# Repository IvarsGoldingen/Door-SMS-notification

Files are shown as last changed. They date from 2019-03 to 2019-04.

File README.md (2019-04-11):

# Door SMS notification

A device that sends an SMS notification when a door is opened. Setup on Atmega Atmel 328P arduino prototyping board together with SIM900 board. The schematic, part layout on the prototyping board and code included in this repository.

## Functions

* SMS notification of door opened event;
* 3 modes: send always, never send, send depending on time;
* Uses RTC on the SIM900 module to evaluate if SMS needs to be sent or not if sending depending on time enabled;
* Sends notification if battery gets low;
* Indication lights.

## Photos



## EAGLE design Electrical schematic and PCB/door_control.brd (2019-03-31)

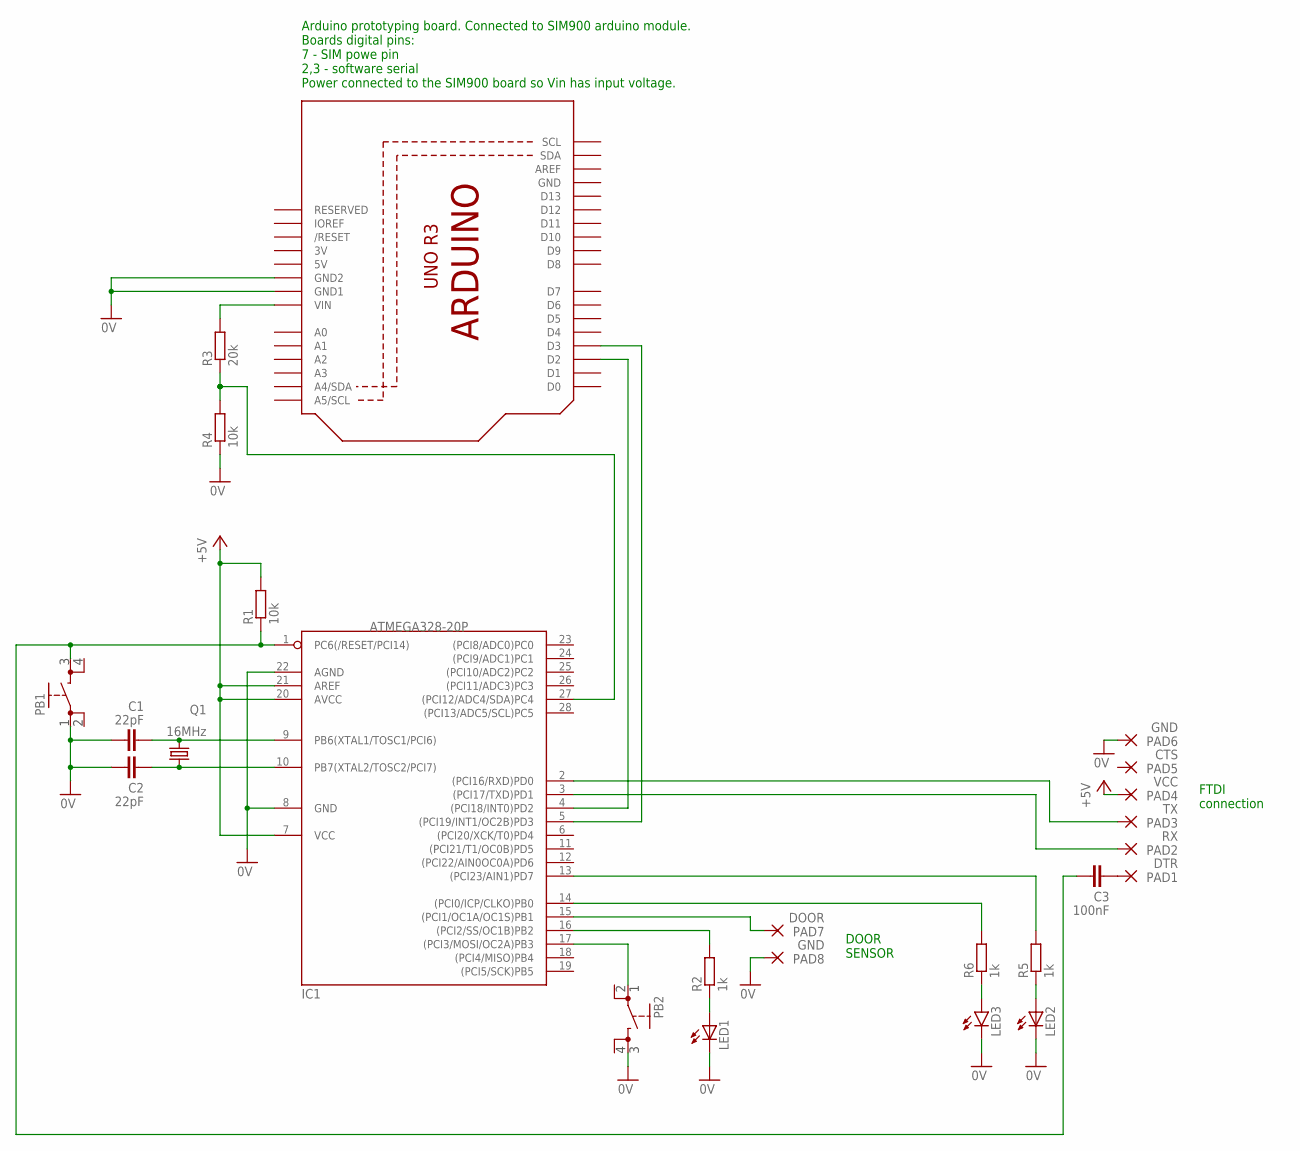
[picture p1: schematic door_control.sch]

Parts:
C1, C2: 22pF; C5B2.5
C3: 100nF; C10B4
IC1: ATMEGA328-20P; DIL28-3
LED1, LED2: LED_ELD260; LED_LD260
LED3: LED5MM
PAD1: DTR; 1,6/0,9
PAD2: RX; 1,6/0,9
PAD3: TX; 1,6/0,9
PAD4: VCC; 1,6/0,9
PAD5: CTS; 1,6/0,9
PAD6, PAD8: GND; 1,6/0,9
PAD7: DOOR; 1,6/0,9
PB1, PB2: 4P_BUTTONTH; 4P_BUTTON
Q1: 16MHz; HC49/S
R1: 10k; 0207/10
R2, R5, R6: 1k; 0204/5
R3: 20k; 0204/5
R4: 10k; 0204/5
U1: ARDUINOR3-DIMENSION; ARDUINOR3

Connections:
0V: C1.1, C2.1, IC1.8 (GND), IC1.22 (AGND), LED1.K (C), LED2.K (C), LED3.K (C), PAD6.1, PAD8.1, PB1.1, PB2.3, R4.1, U1.GND1, U1.GND2
3V: U1.3V
5V: U1.5V
+5V: IC1.7 (VCC), IC1.20 (AVCC), IC1.21 (AREF), PAD4.1, R1.2
GND: U1.GND
unnamed: C1.2, IC1.9 (PB6(XTAL1/TOSC1/PCI6)), Q1.2
unnamed: C2.2, IC1.10 (PB7(XTAL2/TOSC2/PCI7)), Q1.1
unnamed: C3.1, IC1.1 (PC6(/RESET/PCI14)), PB1.3, R1.1
unnamed: IC1.3 ((PCI17/TXD)PD1), PAD2.1
unnamed: IC1.2 ((PCI16/RXD)PD0), PAD3.1
unnamed: C3.2, PAD1.1
unnamed: IC1.15 ((PCI1/OC1A/OC1S)PB1), PAD7.1
unnamed: LED1.A, R2.1
unnamed: IC1.4 ((PCI18/INT0)PD2), U1.D2
unnamed: IC1.17 ((PCI3/MOSI/OC2A)PB3), PB2.1
unnamed: IC1.5 ((PCI19/INT1/OC2B)PD3), U1.D3
unnamed: IC1.27 ((PCI12/ADC4/SDA)PC4), R3.1, R4.2
unnamed: R3.2, U1.VIN
unnamed: IC1.13 ((PCI23/AIN1)PD7), R5.2
unnamed: LED2.A, R5.1
unnamed: IC1.14 ((PCI0/ICP/CLKO)PB0), R6.2
unnamed: LED3.A, R6.1
unnamed: IC1.16 ((PCI2/SS/OC1B)PB2), R2.2

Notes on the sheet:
FTDI connection
DOOR SENSOR
Arduino prototyping board. Connected to SIM900 arduino module. Boards digital pins: 7 - SIM powe pin 2,3 - software serial Power connected to the SIM900 board so Vin has input voltage.

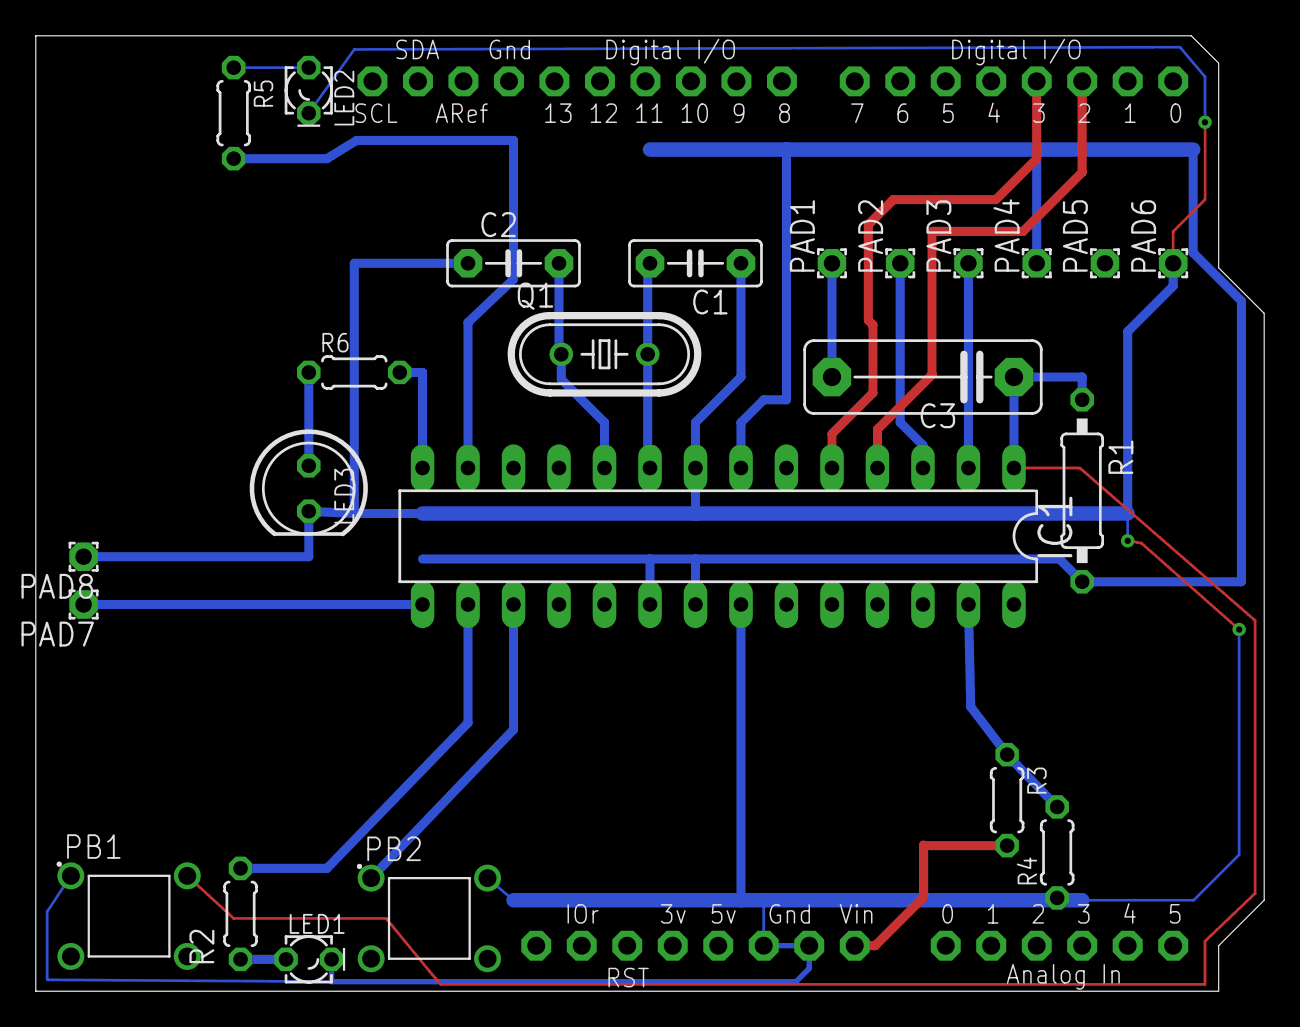
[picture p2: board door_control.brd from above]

Board: 2 copper layers, 68.6 x 53.3 mm, 25 parts (0 on the bottom side), 20 nets.

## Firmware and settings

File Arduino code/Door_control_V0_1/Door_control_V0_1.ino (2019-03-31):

/*
 * DOOR CONTROL v0.1
 * Sketch sends SMS using sim900 module, when a door is opened
 * Sending possible in 3 modes: send always, send depending on time(RTC on SIM900), dont send
 * Button for togling modes
 * Manual control through serial available
 * TODOs:
 * Implement logging on SD card. Slot available on SIM module
 * Clock sysnc using SIM
 */

#include "Sim.h"
#include "ButtonIB.h"
#include "LedControl.h"

//Pin used to enable disable the SIM module
const byte SIM_ENABLE_P = 4;

//Voltage input connected to arduino with a voltage divider. I am using 10k and 20k.
//So the voltage read on the input is one third of the actual voltage
const byte VOLTGE_DIVIDER_K = 3;
//Voltage input pin
const byte V_PIN = 4;
//time between voltage measurements in s (If timer1 interrupt set to happen once a second)
const int V_RD_DLY = 900;//900/60=15min
//Values used to calculate the actual volts read on the analog input
const float VOLTS_PER_UNIT = 5.0/1023.0;
//Minumum voltage level, error message sent otherwise
const float MINIMUM_VOLTAGE = 5.0;

/**Status indication values**/
//Green led output. Const on SIM900 ready, blinking setting up
const int STATUS_LED_O = 8;
//Const on, when sim900 fails to setup
const int ERROR_LED_O = 7;

//Pins that will be used for the software serial to communicate with the sim900 chip
const byte SW_SERIAL_PIN1 = 2;
const byte SW_SERIAL_PIN2 = 3;

//Pin used for send mode change
const byte MODE_BUTTON = 11;
//Pin used for signaling of the current send mode of the system
const byte MODE_LED = 10;

//Door trigger values
const byte DOOR_SENSOR_P = 9;

//Minimum time necessary for the door open to be registered as an event.
const int MINIMUM_SWITCH_TIME = 1000;
//Set minimum time between door events 
//5 minutes = 5m * 60s * 1000ms = 300 000
const float DELAY_FOR_DOOR_EVENTS = 60000;

//Time constraints for when the sms is being sent
//returns 1 for Sunday, 2 for Monday, etc., up to 7 for Saturday
//the 2nd youngest bit represents Sunday, the oldest bit represents Saturday, the youngest bit does not represent anything
const byte SEND_WEEKDAYS = 0b01111100;
//Time of day from which SMS are sent on appropriate weekdays
const byte SEND_TIME_H_START = 8;
//Time of day from which SMS are np longer sent on approptiate weekdays
const byte SEND_TIME_H_END = 17;

//Manual control characters for serial port
//to set the time use this format x19/03/09,11:56:55+08,<yy/MM/dd,hh:mm:ss±zz> +08 for gmt+2,
//module must be on and initialized, that must be done mannualy before
const char SET_TIME_CHAR = 'x';
//returns the time stored in the sim module's RTC
const char GET_TIME_CHAR = 'y';
//change modes from don't send, send always, send depending on time
const char CHANGE_MODE_CHAR = 'm';
//turn module on and set PIN code
const char INIT_CHAR = 'e';
//turn module off
const char OFF_CHAR = 'o';
//sends test message when module is already initialized
const char TEST_MESSAGE_CHAR = 'w';
//full sequence, on, init, get time, send message, turn off
const char SEND_SEQUENCE_CHAR = 'a';

// 3 modes for sending
//Send depending on time
const byte SEND_TIME = 1;
//Send allways
const byte SEND_ALWAYS = 2;
//don't send
const byte SEND_OFF = 3;
//don't send
const byte LOW_BAT = 4;

//Set true when input voltage should be read
volatile bool readV = false;
//counter of timer interrupts to compare to with the V-RD_DLY int the ISR
volatile int vDlyCntr = 0;
//battery low indication
bool batteryLow = false;

bool doorTriggered = false;
//variable to store time since the last door moved, used for debounce
//set to negative MINIMUM_SWITCH_TIME so works instantly on startup
long doorMoveTime = -MINIMUM_SWITCH_TIME;
////variable to store time since the last door moved, used for setting delay between SMS sends 
long doorTriggerTime = -DELAY_FOR_DOOR_EVENTS;

//Made true when door is triggered
//when true the sim chip will get turned on, sms sent, then turned off
bool sending = false;
//variable of keeping track of the sending mode
byte sendMode = SEND_TIME;

//A buffer where the neccessary message is stored. At this point either "Door triggered" or battery low "possible"
char messageBuffer[16];

/*********************************************************************************
callback from the SIM library
must be declared before the contructur so the function is visible to it
Will inform the main scetch of finished actions and errors
possible status updates from Sim lib to main sketch
    const byte INIT_FINISHED = 1;
    const byte INIT_FAILED = 2;
    const byte SMS_SENT = 3;
    const byte SMS_SEND_FAILED = 4;
    const byte TUREND_OFF = 5;
*/
void updateCallback(byte message){
  Serial.println("CB");
  if (sending){
    //if sending started use info from SIM to send the message
    sendSequence(message);
  }
}

/*********************************************************************************
callback from the SIM library
must be declared before the contructur so the function is visible to it
sends time from SIM module's RTC
*/
void timeCallback(String simTime){
  //remove time zone from the string, which starts from index 17
  simTime.remove(17);
  Serial.println(simTime);
  if (sending){
    //determine what type of message is being sent
    if (messageBuffer[0] == 'D'){
      //A door triggered message is being sent
      //needs to be evaluated against modes and possibly time
      bool sendSMS = false;
      if (sendMode == SEND_OFF){
        Serial.println("Sending mode off");
      } else if (sendMode == SEND_TIME){
        sendSMS = evaluateSend(simTime);
      } else if (sendMode == SEND_ALWAYS){
        sendSMS = true;
        Serial.println("Sending mode allways");
      }
      if(sendSMS){
        Serial.println("Sending");
        float inputVoltage = readInputVoltage();
        //sendSms((char*)messageBuffer + '_' + simTime + '_' + "V:" + String(inputVoltage));
        String temp(messageBuffer);
        String fullMessage = temp + "\n" + simTime + "\nV: " + String(inputVoltage);
        Serial.println(fullMessage);
        sendSms(fullMessage);
      } else {
        stopSim();
        Serial.println("Not sending");
      }
      
    } else if (messageBuffer[0] == 'B'){
      //A battery low meessage is being sent
      float inputVoltage = readInputVoltage();
      String temp(messageBuffer);
      String fullMessage = temp + "\n" + simTime;
      Serial.println(fullMessage);
      sendSms(fullMessage);
    } else {
      Serial.println("Unknown message in message buffer");
    }
    
     
  }
}

//Create a Sim object to control the Sim900 chip
Sim sim(SW_SERIAL_PIN1,SW_SERIAL_PIN2,STATUS_LED_O,ERROR_LED_O, updateCallback, timeCallback);

//calback from the button object when a button is pressed
void modeButtonPressed(){
  //allow the button to override the low bat condition
  batteryLow = false;
  switchSendMode();
}

//A button object for receiving the mode change pressses
ButtonIB modeButton(MODE_BUTTON, modeButtonPressed);

LedControl modeLed(MODE_LED);

//Evaluates if sending of SMS is neccessary depending on send mode and time
//TODO: check only time here, and check for send off earlier
bool evaluateSend(String simTime){
  Serial.println("Evaluating send time");
   //-48 because the received number is from ASCII table not numeric
  byte year = ((simTime[0] - 48) * 10) + (simTime[1] - 48);
  byte month = ((simTime[3] - 48) * 10) + (simTime[4] - 48);
  byte day = ((simTime[6] - 48) * 10) + (simTime[7] - 48);
  byte hour = ((simTime[9] - 48) * 10) + (simTime[10] - 48);
  //byte minute = ((simTime[12] - 48) * 10) + (simTime[13] - 48);
  //byte second = ((simTime[15] - 48) * 10) + (simTime[16] - 48);
  byte weekDay = calcDayOfWeek(year, month, day);
  bool sendSMS = false;
  Serial.println(SEND_WEEKDAYS & (0b00000001 << weekDay));
  if((SEND_WEEKDAYS & (0b00000001 << weekDay)) > 0){
    Serial.println("Weekday");
    if(hour >= SEND_TIME_H_START &&
      hour < SEND_TIME_H_END){
      Serial.println("Working time");
      sendSMS = true;
    } else {
      Serial.println("Past working time");
    }
  } else {
    Serial.println("Weekend");
  }
  return sendSMS;
}

void sendSms(String text){
  sim.sendMessage(text);  
}
 
void setup() {
  //Initiate serial with the computer
  Serial.begin(115200);
  //Setup the door input sensor
  pinMode(DOOR_SENSOR_P, INPUT_PULLUP);
  //Turn the sim module off on startup
  digitalWrite(SIM_ENABLE_P, LOW);
  //set the mode led on initally, because the modeule starts up with ALWAYS_SEND mode
  modeLed.ledOn();    
  Serial.println("ON");

  //Setup timer1 interrupt for timeing when voltage input should be read
  //These registers must be set to 0 for the timer to work
  TCCR1A = 0;
  TCCR1B = 0;
  //Set the actual timer counter value to 0
  TCNT1  = 0;
  // The compare register, when this count will be reached the interruptwill happen
  OCR1A = 15625;
  //set mode of timer to CTC- Clear Timer on Compare match
  TCCR1B |= (1 << WGM12);
  //set the prescaler. 101 = 1024
  TCCR1B |= (1 << CS12);     
  TCCR1B |= (0 << CS11);    
  TCCR1B |= (1 << CS10);
  //enable timer compare interrupt
  TIMSK1 |= (1 << OCIE1A);
  /*
   * CPU freq devided by prescaler
   * 16000000/1024 = 15625
   * Devide result with set compare result
   * 15625/15625=1 Hz
   * 1 s intervals between interrupt calls
   */        
}


void loop() {
  manualControl();
  sim.loop();
  modeButton.loop();
  modeLed.loop();
  if(!sending && !batteryLow){
    //if we are not sending already, check for door trigger
    if(checkDoorOpen()){
      //Door opened
      if (timePassed(doorTriggerTime) > DELAY_FOR_DOOR_EVENTS){
        //Enough time has passed since the last send sequence
        Serial.println("Start SMS send sequence");
        //Write the message we want into the messageBuffer
        String message = "Door";
        message.toCharArray(messageBuffer, 16);
        //store when the SMS sending was started to allow for delays between sends
        doorTriggerTime = millis();
        //Start send sequence
        startSendSequence();
      } else {
        Serial.println("Door delay active");
      }
    } else if (readV){
      //Set this to false to wait for the next read. It is set true in the timer1 ISR
      readV=false;
      checkVoltage();
    }
  }
}

//checks if voltage is not too low and if it is starts SMS send sequence
void checkVoltage(){
  float inputVoltage = readInputVoltage();
  Serial.print("Voltage read: ");
  Serial.println(inputVoltage);
  if (inputVoltage < MINIMUM_VOLTAGE){
    String message = "Bat low: " + (String)inputVoltage;
    Serial.println(message);
    message.toCharArray(messageBuffer, 16);
    startSendSequence();
    batteryLow = true;
    modeLed.ledBlink(100);
  } else {
    Serial.println("Bat ok");
  }  
}

//turn off sending of SMS and turns the sim chip of
void stopSim(){
  sim.off();
  sending = false;
}

//When status messages come in from the SIM module, make next steps for sending
void sendSequence(byte simStatus){
  //the first status mesages from sim will be about initialization finished or failed
  switch(simStatus){
    case sim.INIT_FINISHED:
      Serial.println("SIM INIT SUCCESS");
      //if init has finished, get the time 
      sim.getTime();
      break;
    case sim.INIT_FAILED:
      //if init failed 
      stopSim();
      //TODO: perharps try resending
      //TODO: distinguish errors that mean no SIM card etc, and errors that might allow for resending
      Serial.println("Init failed");
      break;
    case sim.SMS_SENT:
      //if init succesfull turn of sim module
      Serial.println("SMS_SUCCESS"); 
      stopSim();
      break;
    case sim.SMS_SEND_FAILED:
      //if sending failed 
      stopSim();
      Serial.println("send failed");
      break;
    case sim.TUREND_OFF:
      break;
    default:
      Serial.println("CB UM");
      break;
  }
}


//returns true if door switch has been triggered
bool checkDoorOpen(){
  if (!doorTriggered){
    //if the door has not yet been triggered
    // read door sensor. Reverso so true is for triggered
    if (digitalRead(DOOR_SENSOR_P)){
      //Door opened
      if (timePassed(doorMoveTime) > MINIMUM_SWITCH_TIME){
      //debounce time has passed
        Serial.println("Door open");
        //if the door sensor has been activated, chech the time
        doorMoveTime = millis();
        doorTriggered = true;
        //send true so SMS sending starts
        return true;
      }
    }
  } else if (!digitalRead(DOOR_SENSOR_P)){
    //if the door has been closed again allow for the next listen
    doorTriggered = false;
  }
  return false;
}

//calculates time passed from the time sent to the function
long timePassed(long time){
  return millis() + ((-1) * time);
}


//allows control of sim with serial port
void manualControl(){
  if(Serial.available()){
    Serial.println("man");
    while(Serial.available()){
      char pcChar = Serial.read();
      if (pcChar == INIT_CHAR){
        //0x1A is needed to send an SMS, Y used to be able to send it through terminal
        sim.setupSim();
      } else if (pcChar == OFF_CHAR) {
        Serial.println("off");
        sim.off();
      } else if (pcChar == TEST_MESSAGE_CHAR) {
        sim.sendMessage("Test");
      } else if (pcChar == SEND_SEQUENCE_CHAR) {
        startSendSequence();
      } else if (pcChar == SET_TIME_CHAR){
        //delay to receive all the sent bytes from serial
        delay(10);
        //20 bytes needed for setting of the time
        byte timeBuffer[20];
        byte timeBufferCount = 0;
        //if setting the time, read the whole message from the serial buffer
        while(Serial.available()){
           timeBuffer[timeBufferCount++] = Serial.read();
           //with baud 9600, byte lenght about 1 ms, so wait for 5 do make sure all symbols are read before exiting the loop
           delay(10);
        }
        if (timeBufferCount == 20){
          //the correct number of bytes is 20 for setting the time
          //TODO: check the time format deeper or use reading answer messages from SIM900
          sim.setTime(timeBuffer);
        } else {
          Serial.print("TIME FORMAT ERROR ");
          Serial.println(timeBufferCount);
        }
      } else if (pcChar == GET_TIME_CHAR){
        sim.getTime();
      } else if (pcChar == CHANGE_MODE_CHAR){
        switchSendMode();
      }
    }
  }
}

//Starts the send sequence which is: turn sim on, init, send, off
void startSendSequence(){
  //Initiate sim setup
  sim.setupSim();
  //The scetch will auomatically send the message when sim has been initialized
  sending = true;
}

/*
 * changes the mode of sending between send always, send depending on time, don't send
 * sets the status led as well
 */
void switchSendMode(){
  //switch mode of sending (1-3)
  sendMode++;
  switch(sendMode){
    case SEND_TIME:
      //led const on when sending depending on time
      modeLed.ledOn();
      break;
    case SEND_ALWAYS:
      //led blinking when sending always
      modeLed.ledBlink(500);
      break;
    case SEND_OFF:
      //led off when sending always
      modeLed.ledOff();
      break;
    default:
      //set to SEND_TIME, which is 1, so the ++ works
      sendMode = SEND_TIME;
      modeLed.ledOn();
      break;
  }
  Serial.print("Send mode: ");
  Serial.println(sendMode);
}

//Reads and returns input voltage on the set pin
float readInputVoltage(){
  //Read analog input
  int anReadV = analogRead(V_PIN);
  //Calculate the voltage on the analog pin
  float votlage = anReadV*VOLTS_PER_UNIT;
  //Calculate the actual input voltage which is dependant on the voltage divider
  float inputVoltage = votlage*VOLTGE_DIVIDER_K;
  return inputVoltage;
}

//calculates the day of week from date
byte calcDayOfWeek (byte y, byte m, byte d) {
  // Old mental arithmetic method for calculating day of week
  // adapted for Arduino, for years 2000~2099
  // returns 1 for Sunday, 2 for Monday, etc., up to 7 for Saturday
  // for "bad" dates (like Feb. 30), it returns 0
  // Note: input year (y) should be a number from 0~99
  if (y > 99) return 0; // we don't accept years after 2099
  // we take care of bad months later
  if (d < 1) return 0; // because there is no day 0
  byte w = 6; // this is a magic number (y2k fix for this method)
  // one ordinary year is 52 weeks + 1 day left over
  // a leap year has one more day than that
  // we add in these "leftover" days
  w += (y + (y >> 2));
  // correction for Jan. and Feb. of leap year
  if (((y & 3) == 0) && (m <= 2)) w--;
  // add in "magic number" for month
  switch (m) {
    case 1:  if (d > 31) return 0; w += 1; break;
    case 2:  if (d > ((y & 3) ? 28 : 29)) return 0; w += 4; break;
    case 3:  if (d > 31) return 0; w += 4; break;
    case 4:  if (d > 30) return 0; break;
    case 5:  if (d > 31) return 0; w += 2; break;
    case 6:  if (d > 30) return 0; w += 5; break;
    case 7:  if (d > 31) return 0; break;
    case 8:  if (d > 31) return 0; w += 3; break;
    case 9:  if (d > 30) return 0; w += 6; break;
    case 10: if (d > 31) return 0; w += 1; break;
    case 11: if (d > 30) return 0; w += 4; break;
    case 12: if (d > 31) return 0; w += 6; break;
    default: return 0;
  }
  // then add day of month
  w += d;
  // there are only 7 days in a week, so we "cast out" sevens
  while (w > 7) w = (w >> 3) + (w & 7);
  return w;
}

// timer compare interrupt service routine
//used to determine if time to read the voltage input
ISR(TIMER1_COMPA_vect)          
{
  vDlyCntr++;
  if (vDlyCntr >= V_RD_DLY){
     vDlyCntr = 0;
     readV = true;
  }
}

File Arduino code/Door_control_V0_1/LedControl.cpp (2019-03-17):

//This needs to be included in the library so it can access standard arduino functions
#include "Arduino.h"
#include "LedControl.h"

//A constructor for the class
LedControl::LedControl(byte pin){
  ledPin = pin;
  pinMode(pin, OUTPUT);
}

void LedControl:: ledOn(){
  digitalWrite(ledPin, HIGH);
  blinkOn = false;
}

void LedControl:: ledOff(){
  digitalWrite(ledPin, LOW);
  blinkOn = false;
}

void LedControl::ledBlink(unsigned int timeMs){
  blinkTime = timeMs;
  blinkOn = true;
  timeOfLastSwitch = millis();
}

void LedControl::loop(){
  if (blinkOn){
    if (millis() - timeOfLastSwitch > blinkTime){
      timeOfLastSwitch = millis();
      digitalWrite(ledPin, !digitalRead(ledPin));
    }
  }
}

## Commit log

2019-03-09 Minor fixes
    Tested with actual devices
    [Door_control_V0_1.ino, Sim.cpp, Sim.h]
2019-03-17 Working beta
    First stable version, device sends SMS on door open. Sending depending on time implemented.
    Mode change button implemented.
2019-03-24 Input voltage read
    The device now also sends a SMS message if the input voltage gets too low. For battery protection.
    [Door_control_V0_1.ino, Sim.cpp]
2019-03-31 Schematic added
    Project moved from Arduino UNO to Arduino prototyping board with Atmega328P. Pins in code changed accordingly.
    [door_control.brd, door_control.sch]
